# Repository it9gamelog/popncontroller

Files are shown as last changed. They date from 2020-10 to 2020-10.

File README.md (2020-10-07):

# Pop'n Arcade Controller

Please see the video for the making of and some explaination:
https://github.com/it9gamelog/it9gamelog/wiki/Pop'n-Controller

# License

MIT License

# Software Requirements

* Firmware: Arduino 1.8.13 + Arduino Micro
* PCB: KiCad
* Mechanical: Solidworks

# Known Bugs

* The big button might have two M3 lugs on the side for asserting rotation motion, which the mechanical model didn't consider.

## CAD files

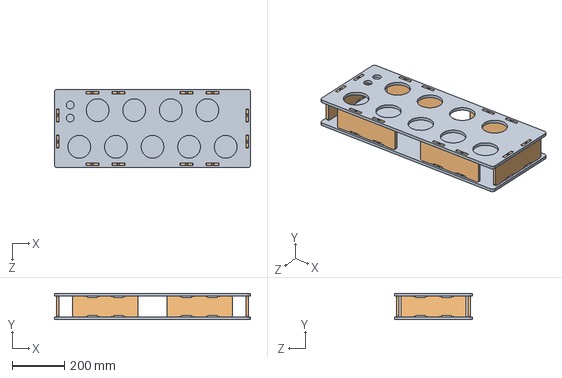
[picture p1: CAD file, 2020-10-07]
mechanical/Popn Controller v2.SLDASM
750.0 x 100.0 x 300.0 mm
Support x 6

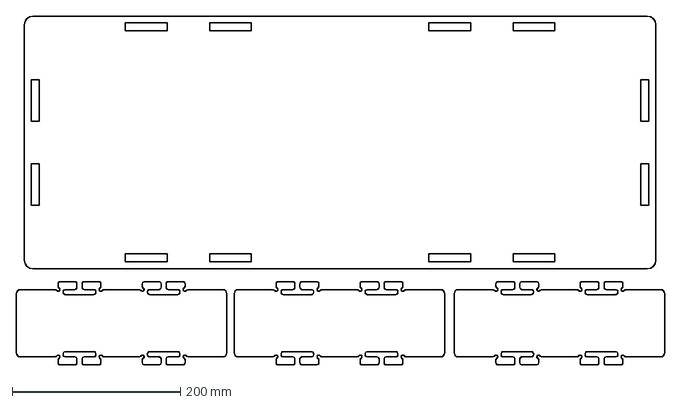
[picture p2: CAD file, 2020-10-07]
mechanical/output/output p2.DXF
770.1 x 414.2 mm

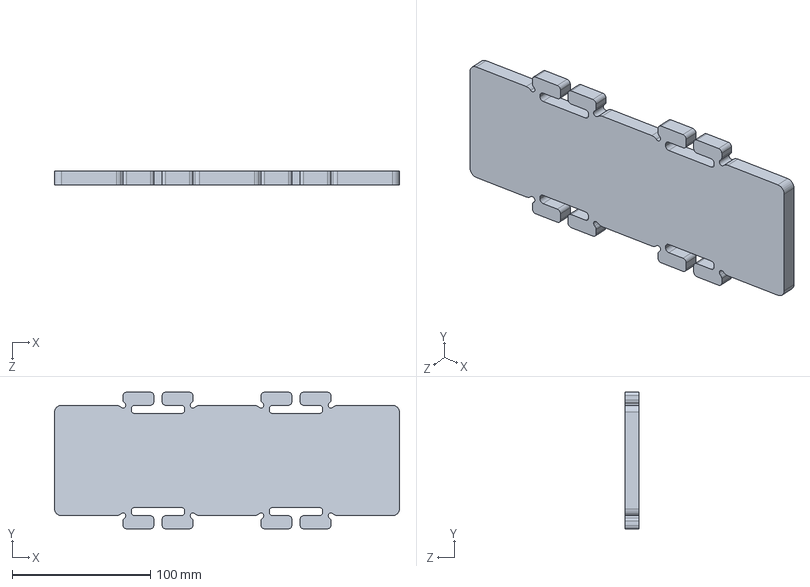
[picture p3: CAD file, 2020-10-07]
mechanical/Support.SLDPRT
250.0 x 99.0 x 10.0 mm

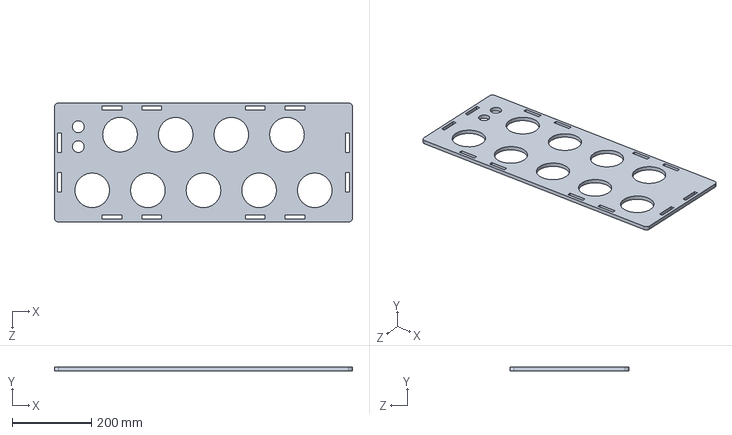
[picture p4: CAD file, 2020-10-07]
mechanical/Face.SLDPRT
750.0 x 10.0 x 300.0 mm

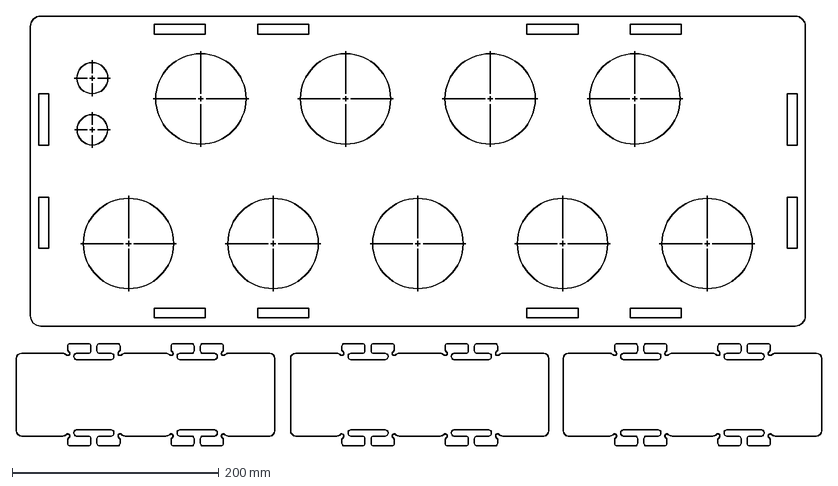
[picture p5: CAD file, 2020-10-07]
mechanical/output/output p1.DXF
779.2 x 415.8 mm

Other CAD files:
mechanical/Output.SLDDRW

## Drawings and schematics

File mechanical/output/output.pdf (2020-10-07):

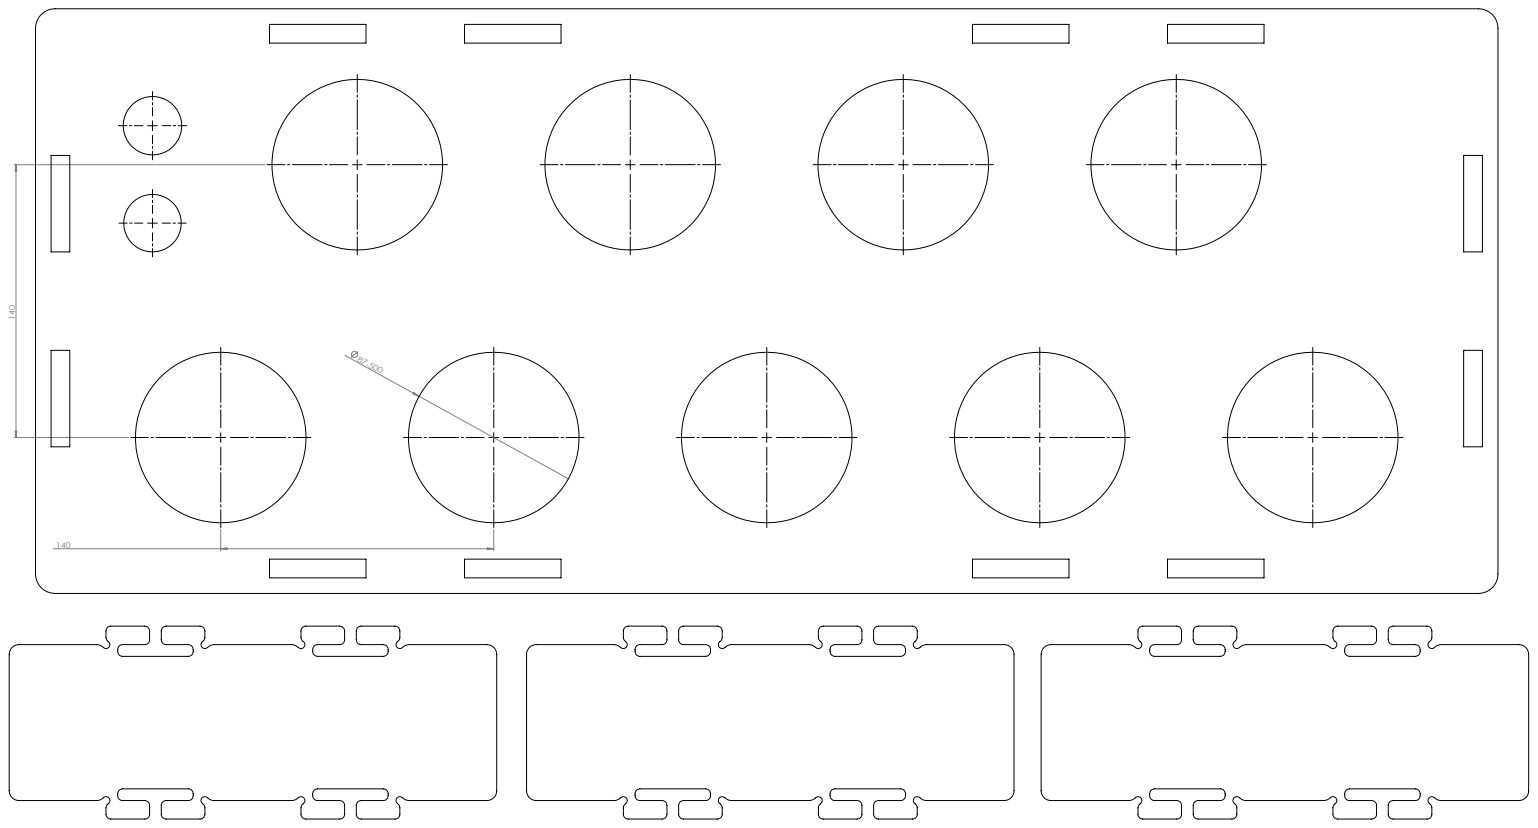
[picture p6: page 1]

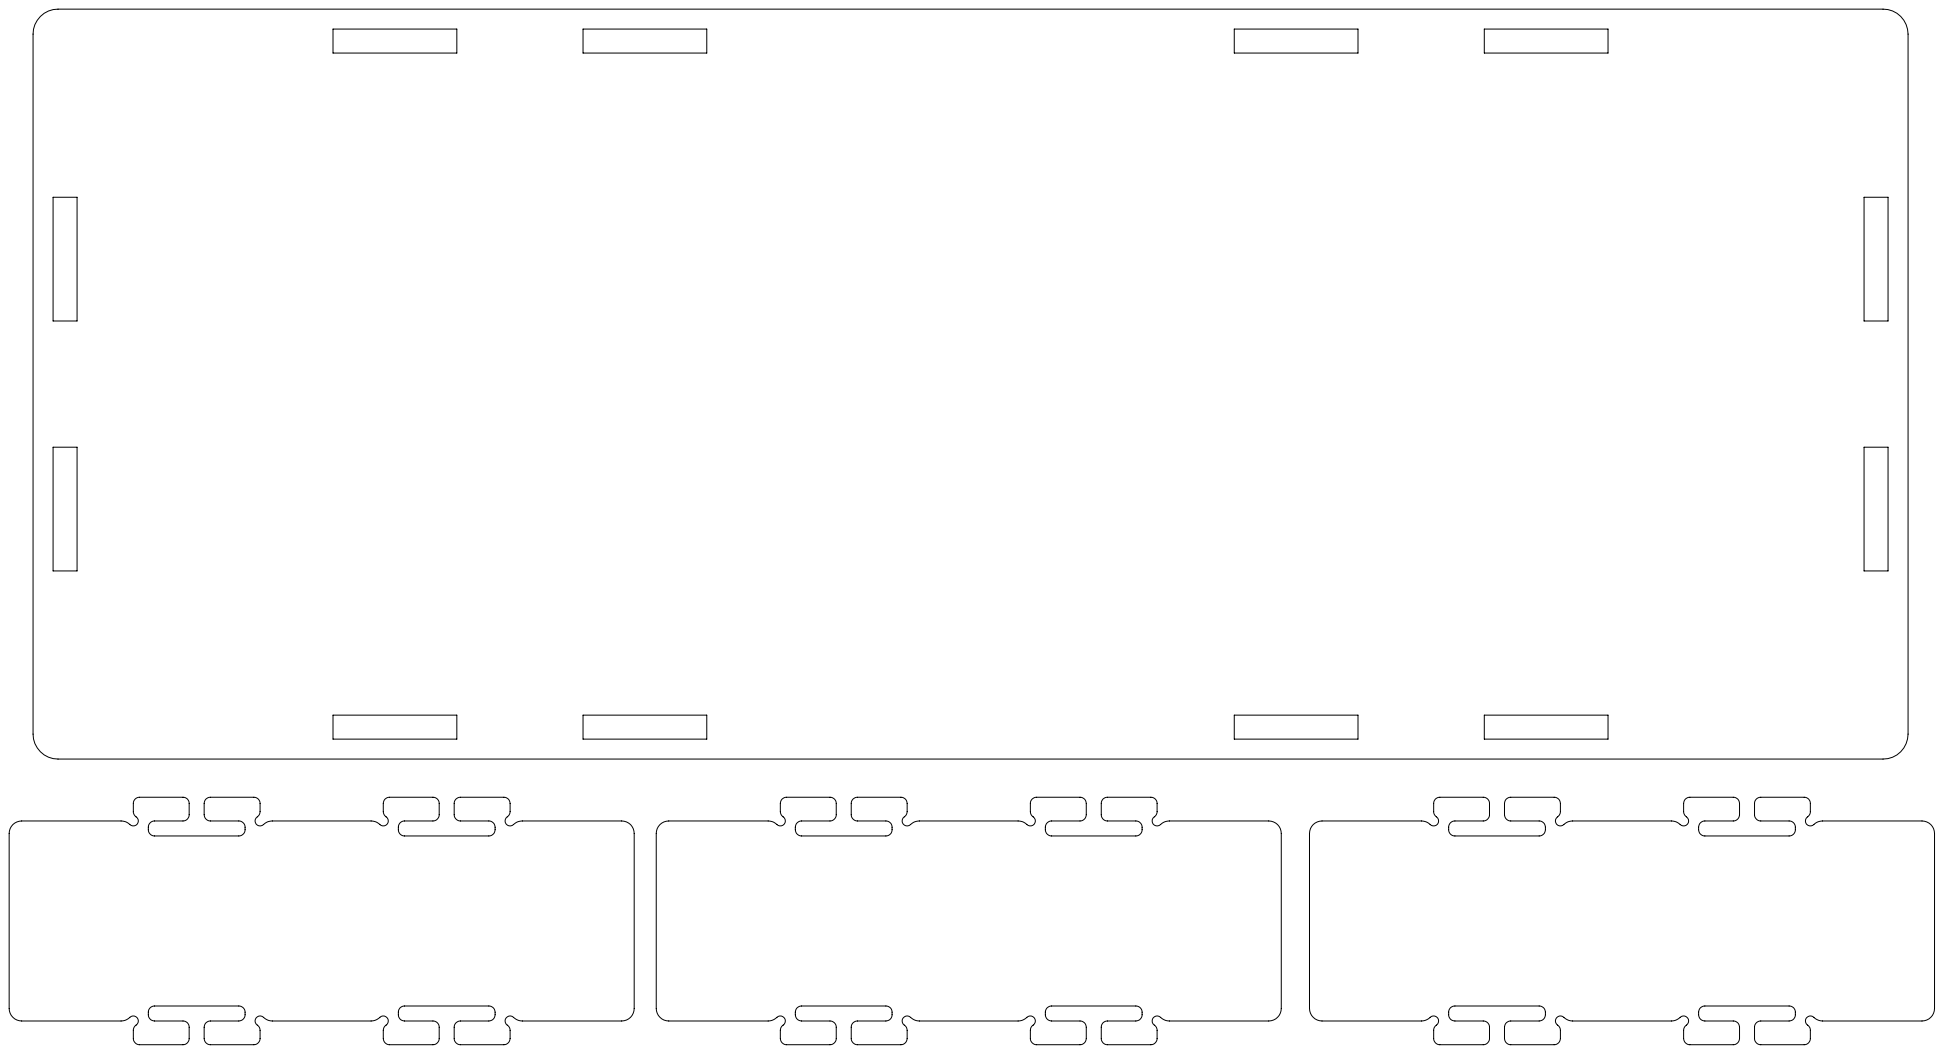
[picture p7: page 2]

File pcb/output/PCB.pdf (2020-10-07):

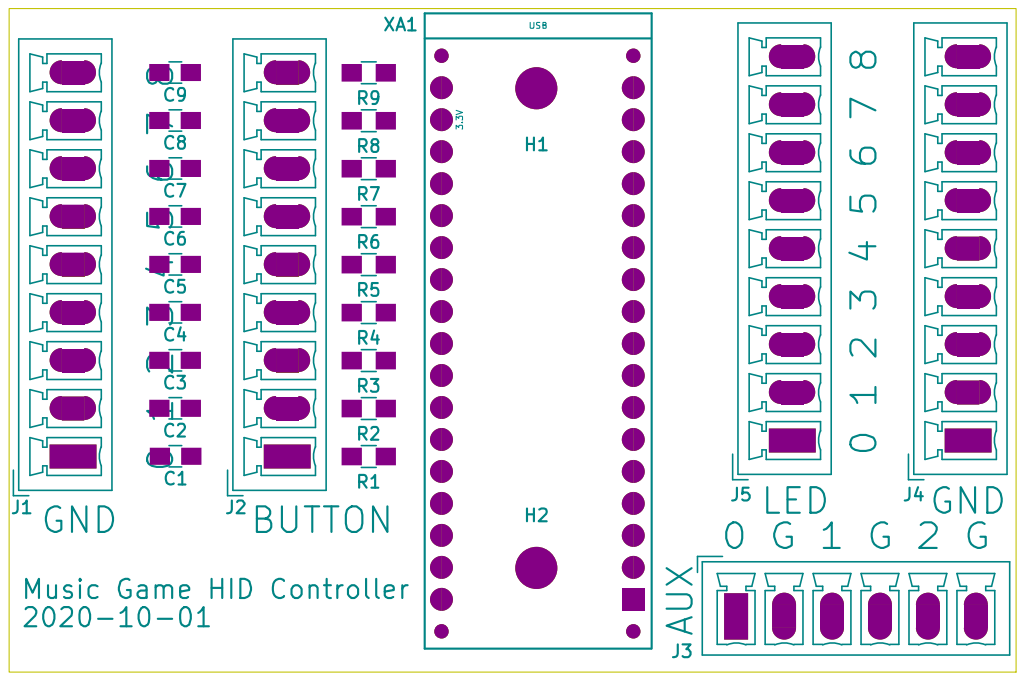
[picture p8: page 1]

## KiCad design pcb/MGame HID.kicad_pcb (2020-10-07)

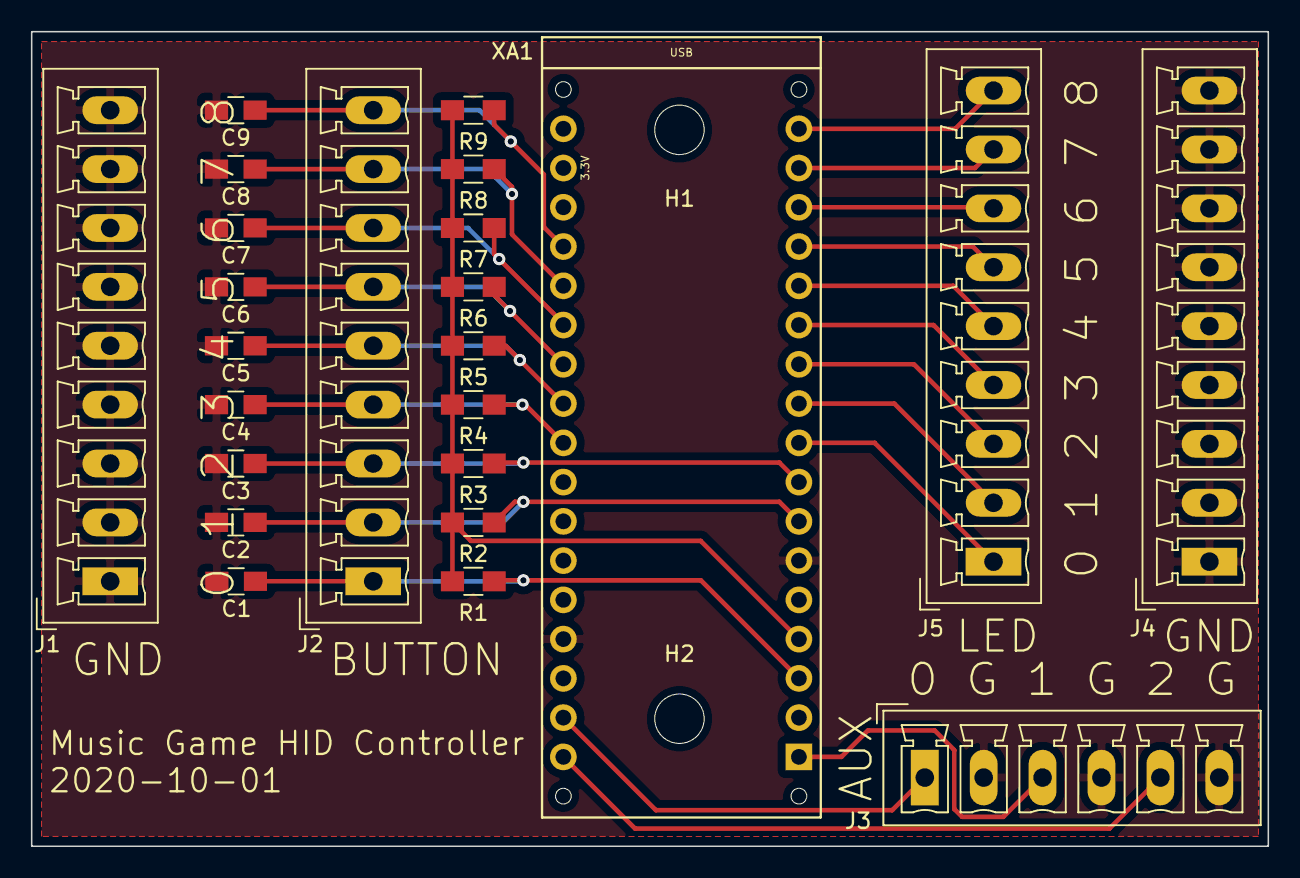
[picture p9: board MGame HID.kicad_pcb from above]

Board: 2 copper layers, 80.0 x 52.7 mm, 26 parts (0 on the bottom side), 23 nets.

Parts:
C1, C2, C3, C4, C5, C6, C7, C8, C9: 20pF; C_0805_HandSoldering
H1, H2: MountingHole; MountingHole_3.2mm_M3
J1, J2, J4, J5: Conn_01x09; PhoenixContact_MCV-G_09x3.81mm_Vertical
J3: Conn_01x06; PhoenixContact_MCV-G_06x3.81mm_Vertical
R1, R2, R3, R4, R5, R6, R7, R8, R9: 680K; R_0805_HandSoldering
XA1: Arduino_Micro_Socket

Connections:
/AUX0: J3.1, XA1.MISO
/AUX1: J3.3, XA1.MOSI
/AUX2: J3.5, XA1.SCK
/BUT0: C1.1, J2.1, R1.2, XA1.D1
/BUT1: C2.1, J2.2, R2.2, XA1.D2
/BUT2: C3.1, J2.3, R3.2, XA1.D3
/BUT3: C4.1, J2.4, R4.2, XA1.A5
/BUT4: C5.1, J2.5, R5.2, XA1.A4
/BUT5: C6.1, J2.6, R6.2, XA1.A3
/BUT6: C7.1, J2.7, R7.2, XA1.A2
/BUT7: C8.1, J2.8, R8.2, XA1.A1
/BUT8: C9.1, J2.9, R9.2, XA1.A0
/LED0: J5.1, XA1.D4
/LED1: J5.2, XA1.D5
/LED2: J5.3, XA1.D6
/LED3: J5.4, XA1.D7
/LED4: J5.5, XA1.D8
/LED5: J5.6, XA1.D9
/LED6: J5.7, XA1.D10
/LED7: J5.8, XA1.D11
/LED8: J5.9, XA1.D12
GND: C1.2, C2.2, C3.2, C4.2, C5.2, C6.2, C7.2, C8.2, C9.2, J1.1, J1.2, J1.3, J1.4, J1.5, J1.6, J1.7, J1.8, J1.9, J3.2, J3.4, J3.6, J4.1, J4.2, J4.3, J4.4, J4.5, J4.6, J4.7, J4.8, J4.9, XA1.GND1, XA1.GND2
unnamed: R1.1, R2.1, R3.1, R4.1, R5.1, R6.1, R7.1, R8.1, R9.1, XA1.D0

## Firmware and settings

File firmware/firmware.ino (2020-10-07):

/*
 * Pop'n Arcade Controller
 * https://github.com/it9gamelog/popncontroller
 *
 * MIT License
 * 
 * Copyright (c) 2020 IT9GameLog
 * 
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
 * THE SOFTWARE IS PROVIDED "AS IS", WITHOUT WARRANTY OF ANY KIND, EXPRESS OR
 * IMPLIED, INCLUDING BUT NOT LIMITED TO THE WARRANTIES OF MERCHANTABILITY,
 * FITNESS FOR A PARTICULAR PURPOSE AND NONINFRINGEMENT. IN NO EVENT SHALL THE
 * AUTHORS OR COPYRIGHT HOLDERS BE LIABLE FOR ANY CLAIM, DAMAGES OR OTHER
 * LIABILITY, WHETHER IN AN ACTION OF CONTRACT, TORT OR OTHERWISE, ARISING FROM,
 * OUT OF OR IN CONNECTION WITH THE SOFTWARE OR THE USE OR OTHER DEALINGS IN THE
 * SOFTWARE.
 */

#include "CapacitiveSensor.h"
#include "PopnController.h"

// Button Pins
CapacitiveSensor sensors[] = {
  CapacitiveSensor(0, 1),
  CapacitiveSensor(0, 2),
  CapacitiveSensor(0, 3),
  CapacitiveSensor(0, A5),
  CapacitiveSensor(0, A4),
  CapacitiveSensor(0, A3),
  CapacitiveSensor(0, A2),
  CapacitiveSensor(0, A1),
  CapacitiveSensor(0, A0)
};

// LED Pins
uint8_t led_pins[] = {4, 5, 6, 7, 8, 9, 10, 11, 12};

const auto size = sizeof(sensors) / sizeof(CapacitiveSensor);

void setup() {
  // Serial.begin(9600);
  PopnController.send();
  for (auto i = 0; i < size; i++)
    pinMode(led_pins[i], OUTPUT);
}

void loop() {
  long start = millis();

  // This loop is about 10ms
  // Each takes about 1ms to sense
  for (auto i = 0; i < size; i++)
  {
    int r = sensors[i].sense(15);
    Serial.print(r);
    Serial.print('\t');
    if (r > 35)
    {
      PopnController.press(i);
    } else
    {
      PopnController.release(i);
    }
  }

  // Send latest keyboard report
  PopnController.send();

  // Update LEDs
  uint16_t leds = PopnController.getLeds();
  // Serial.print(leds);  
  for (auto i = 0; i < size; i++)
  {
    digitalWrite(led_pins[i], leds & 1);
    leds >>= 1;
  }

  Serial.println(millis() - start);
}

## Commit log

2020-10-07 Checking in all the works
    [Face.SLDPRT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]
2020-10-07 Ok a seemingly harmless last minute changes broke everything: missing pinMode in CapacitiveSensor code.
